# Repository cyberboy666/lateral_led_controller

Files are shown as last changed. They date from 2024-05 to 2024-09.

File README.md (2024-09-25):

# lateral_led_controller

### hardware network controller for addressable led installations 



- this circuit is distributed by __UNDERSCORES__ - _an open video hardware label_ : it is available to purchase - as a pcb, kit or assembled unit - at [underscores.shop](https://underscores.shop/lateral_led_controller/)
- the schematic for the circuit can be found [here](/hardware/schematic.pdf)
- the pcb gerber files for the lastest version can be found [here](/hardware/gerber_latest.zip)
- interactive BOM is [here](https://htmlpreview.github.io/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)
- consider [donating](https://opencollective.com/underscores) to the underscores project to help us continue creating for the commons

## description

_lateral_led_controller_ is a hardware interface that converts [Art-Net](https://art-net.org.uk/), a network protocol for transmitting DMX data over network, into signals that drive addressable LEDs. it can be combined with mapping software (such as my [artnet_led_mapper](https://github.com/cyberboy666/artnet_led_mapper/)) to send arbitrary video onto an led strip canvas

features include:

- receives artnet data via ETHERNET, WIFI or ACCESS_POINT
- natively drive addressable leds [WS281X](https://www.aliexpress.com/item/4001322411818.html) and [APA102](https://www.aliexpress.com/item/32322326979.html)
- supports up to `8` parallel data outs and up to `12` DMX universes for max control over `2000` leds !
- local web interface for easily configuring network / led settings
- flexible dc power input - between 5v to 12v with low-heat / efficient on-board step-down converter
- open source hardware and firmware - can be customized to meet your specific needs

## background

this controller is a companion to my [artnet_led_mapper](https://github.com/cyberboy666/artnet_led_mapper/) application that converts a video feed into artnet for addressable led strip installations. it was built for [lateral movement](https://cyberboy666.com/lateralmovement/) club nights such as seen here:



you can find some more background on this install and process here: [WORKS IN PROGRESS 04 - talk about controlling addressable leds for art installation](https://videos.scanlines.xyz/w/p/tUhDfYqJJPfjovscNMvFRL) 

## demo video

(https://videos.scanlines.xyz/w/2kwtY8TChY21LKqXwgELue)

## hardware options

<details><summary>hardware options</summary>

besides this controller there are some more bits of hardware you will need to realize an _addressable led installation_ - i will outline some suggestions here based on my experience but this will depend on your specific requirements - feel free to [email me](mailto:tim@cyberboy666.com) if you would like individual consulting on this.

### led strips

this controller is configured to support two types of addressable led strips (more can be added by firmware update):

### __WS281X__

ie [neopixels](https://www.adafruit.com/product/2541),  [WS2813 (5v) or WS2815 (12v)](https://www.aliexpress.com/item/4001322411818.html)

- these strips are cheapest - around 5usd for 60/m on aliexpress
- data to them is sent over a single wire (D) but is quite slow (around _800kbps_)
- this means that a maximum of around 240 of these leds can be addressed in series before the refresh rate drops below 30fps
- this controller is designed to be able to address up to 8 seperate WS281X led strips in parallel (outputs D0-D7 on board) for maximum 1920 number of leds in total



### __APA102__

ie [dotstar](https://www.adafruit.com/product/2574) ,  [SK9822](https://www.aliexpress.com/item/32322326979.html)

- these strips cost more - around 10usd for 60/m on aliexpress
- data to them is sent over two wires : ( __D__ata and __C__lock ) but is _very fast_ - (around _24Mbps_ )
- the controller is designed to address a single APA10 led strip by connecting D0 -> Data, D1 -> Clock
- at those speeds there is no need to have parrallel outputs can easily address 2000 leds in series (may need to look into power injection tho)
- they also claim to draw around 1/5 of the power as WS281X (i havnt tested this myself)



## power supply

we ended up using a switching power supply [like this](https://www.aliexpress.com/item/1005002843829663.html) 

- choose voltage based on your strip type (likely to be either 5v or 12v)
- and then power based on the requirement for total number of leds you are using
- you should power the _lateral_led_controller_ from the same supply thats powering the leds (its designed to safely take 5v - 12v input) or atleast ensure the GNDs are connected
- take note on the recommended power wire thickness based on how much current is passing through it (if you use 12v strips then less current is required and therefore thinner wires)



## light diffusers

for most installation settings it is prefered to use some kind of diffuser to help to evenly distribute light. there are many options and information about this topic online

## wiring and connectors

the data lines from _lateral_led_controller_ uses Pluggable Screw Terminals - standard wire (22awg etc) can connect these lines from controller to the strip



theres also the option to use cat5/6 cables to carry multiple data lines from the _lateral_led_controller_ - these are quite cheap, come in long distances and have twisted pairs which should allow for longer runs



personally i prefer running power lines seperately (on [red+black paired wire](https://www.aliexpress.com/item/4000625095039.html) ) - and using [these kinds](https://www.aliexpress.com/item/1005004267277214.html) of barrel / screw connectors to easily plug in / unplug from the installation



most led strips come with these [SM JST 4](https://www.aliexpress.com/item/1005002516911742.html?) connectors pre-soldered to both ends. one option if you dont want to resolder wires / new connectors onto each strip would be to just get some extra of these and create breakouts



### custom adapter boards

i made two little pcb adatpers that may help you with format convertion also - see below for some examples of how you could wire them







</details>

## software options

<details><summary>software options</summary>

any software that can output artnet over a network can be used with _lateral_led_controller_. some programs i have tested it with include:

- my [artnet_led_mapper](https://github.com/cyberboy666/artnet_led_mapper) application
- [resolume](https://resolume.com/)
- [touch designer](https://derivative.ca/UserGuide/TouchDesigner)
- [QLC+](https://www.qlcplus.org/)

</details>

# documentation

this project is fully _open-source hardware_ - all the files required to build it are included in this repo for free. if you have the time and/or skill you can contribute back by collaborating on / testing new designs, improving these docs, making demo videos/other creative content etc. you can also support the project financially by [donating](https://opencollective.com/underscores) directing, or purchasing through the [web shop](https://underscores.shop).

depending on whether you are going fully diy or buying an assembled and tested unit, some of the following guides will be relavent to you. the flow would be:

## ordering parts

<details><summary><b>parts sourcing guide (w/ notes on pcb fabracation )</b> - start here if you are building fully from scatch or have purchased a pcb</summary>

i try to source all the parts i can from either:
- [tayda](https://www.taydaelectronics.com/) ; cheaper for common parts like resistors etc, also good for mechanical parts like switches and buttons
- [mouser](https://www.mouser.de/) ; has lots more options, speciality video ic's, can sometimes cost more (free shipping on orders over 50euros)
- other ; ocationally there will be parts which will need to be sourced elsewhere - usaully either aliexpress, ebay or amazon etc...

take a look at the [full_bom](/hardware/bom/full_bom.csv) for this project to see where i am sourcing each part from

## import into tayda

- go to the [tayda quick order](https://www.taydaelectronics.com/quick-order/) and in bottom corner choose _add from file_
- select the file [tayda_bom.csv](./hardware/bom/tayda_bom.csv) in the BOM folder (you will have to download it first or clone this repo)
- after importing select _add to cart_
- __NOTE:__ the minimum value for resistors is 10, so you may need to modify these values to add to cart (or if they are already modified here you will need to see the  full_bom for actual part QTY) 

- OPTIONAL: it is a good idea to add some dip-ic sockets and 2.54pin headers/sockets to your tayda order if you dont have them around already

## sourcing other parts

this circuit has a few _specific_ parts that can not be sourced from tayda/mouser:

### WT32-ETH01 micro-controller
we are using a [WT32-ETH01](https://www.aliexpress.com/item/1005007279607510.html) ESP32 controller with the LAN8720A chip / ethernet port already attached - this is because it requires specific routing that is easier to get in a module like this - [heres](https://github.com/egnor/wt32-eth01) some more general info about this uC - it should be easy to find with a search on ali/amazon/ebay/etc - if you get it without header pins you can solder the controller straight on to the pcb (using the castellated edges) 



### MP1584EN_5v_stepdown

another pre-soldered module used in this circuit is this [MP1584EN_5v_stepdown](https://www.aliexpress.com/item/1005006005888518.html) - 3A Step-down 5v

its a useful module that allows a wide range of voltage inputs and is much more efficent than standard linear regulators (so producing less heat - which is important for installation work) - you can also solder the board directly onto our pcb with the castellated edges - take note of the direction indicated by arrow on bottom of module



### WeMos_CH340G_USB_to_SERIAL

since the WT32-ETH01 doesnt have an on-board _usb-to-serial_ on the module for uploading firmware this board is designed to work with this [WeMos_CH340G_USB_to_SERIAL](https://www.aliexpress.com/item/1005006642575408.html) one - we are using this because it outputs the command signals that allow for auto-uploading (so we dont need to manually switch to boot mode every time) - you may need to join some pads with solder on the module to select DTS mode for it to work



Screenshot from 2024-09-06 13-56-25

## terminal jacks

the footprints on the pcb for the data line outputs are spaced for __3.5MM__

- im using [KF2EDG RIGHT ANGLE 3.5MM PLUGGABLE](https://www.aliexpress.com/item/1005005511990041.html) terminals in my kits, but this is up to you - standard screw terminal (non-pluggable) like [this](https://www.aliexpress.com/item/1005001333343844.html) could also fit..



## ordering pcbs

you can support this project by buying individual pcbs from the [shop](https://underscores.shop). if you would rather have pcbs fabricated from gerbers directly the file you need is [here](/hardware/gerber_latest.zip)

- i get my pcbs fabricated from [jlcpcb](https://cart.jlcpcb.com/quote) - 5 is the minumum order per design
- upload the zip file with the `add gerber file` button
- the default settings are mostly fine - set the __PCB Qty__ and __PCB Color__ settings (you can check that the file looks correct with pcb veiwer)
- it may be best to combine orders with other pcbs you want to have fab'd since the shipping can cost more than the items - also orginising group buys is a good way to distribute the extra pcbs /costs 
  
i often use jlcpcb because they are reliable, cheap and give you an option of colours. remember though that the cheapest Chinese fab houses are not always the most ethical or environmently friendly - if you can afford it consider supporting local companies. 

  </details>
  
## assembly guide
  
<details><summary><b>assembly guide</b> - start here if you have purchased a diy kit</summary>

## interactive BOM for build guiding

follow this link to view the [interactive BOM](https://htmlpreview.github.io/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)

## general solder advice

- remember to heat pad first (2-3seconds), then add solder, then continue to heat (1-2seconds)

- Checkout the web-comic [soldering is easy](https://mightyohm.com/files/soldercomic/FullSolderComic_EN.pdf) for more soldering advice

## order of assembly

- both the _WT32-ETH01_ controller and the _MP1584EN_5v_stepdown_ module can be soldered directly to the board using the castellated edges (if you would rather use pins/sockets this is fine also - just be aware you may need to use higher standoffs if also mounting a front panel) - these should be soldered before anything else

- next i would solder the resistors, capictors (take note of direction), diodes, transistors etc

- finally would finish with ic's and interface parts - sockets, buttons etc...

</details>

## firmware guide

<details><summary><b>firmware guide</b> - for editing the code & flashing it to your micro-controller</summary>
  
## flashing firmware onto the micro-controller
  
if you have got a kit from the shop the default firmware will be pre-configured - still it could be useful to know how to update firmware / customize your controller.
  
### install guide
  
all _underscores_ projects with micro-controllers use [platformio](https://platformio.org/) with [visual studio code](https://code.visualstudio.com/) to edit, flash and monitor the code.
  
- first download (and unzip) the code in this repo - easiest is [as a zip](https://github.com/cyberboy666/lateral_led_controller/archive/refs/heads/main.zip) or you can clone using git if you are comfortable with this
- next download, install and open [visual studio code](https://code.visualstudio.com/#alt-downloads)
- now open the extension tab within vscode on left vertical menu (or press ctrl-shift-x) and search for `platformio` to install this extension
  


- connect the micro-controller to computer via usb with the __WeMos_CH340G_USB_to_SERIAL__ port, open the software folder of this project (ctrl-k ctrl-o) in vscode and find the _platformio_ commands (either in left vertical menu under _platformio_ or little tick/arrow symbols along bottom blue bar) - `PlatformIO: Upload` should flash the default code to your micro-controller
  


</details>

</details>

## operating guide
  
<details><summary><b>operating guide</b> - start here if you have purchased an assembled unit</summary>



## access settings interface for first time

- power on the circuit by plugging in a 5-12v dc supply into the POWER IN
- using a computer / phone connect to the ACCESS_POINT created by the controller: default name `leds` pw `ledsleds` - you should see the blue _network connected_ led come on when you have connected to this network
- in a browser go to `http://leds.local` (also try `http://192.168.4.1` if that doesnt work ) - you should now see the web interface!
- from here you can set up which connection mode to use, see your controllers ip and also set which led protocol & layout to use - make sure the led settings (led type, number of data lines and number of leds per line ) reflect your installation setup.
- for most installation settings it will be preferable to use wired ethernet connection to send data into this controller - make sure the IP/SUBMASK/GATEWAY settings reflect the ethernet settings being used on the computer this controller is connecting to. __auto assign ethernet connection__ worked from my linux machine but i could not get windows to assign an ip (act as dhcp) - maybe there is some setting or maybe it needs to be done manually from some operating systems such as windows.





## reset button

### soft reset

on the controller board next to the `NETWORK CONNECTED` led is a `CONTROLLER RESET` button - pushing this will reboot the controller -> you should see the _network connected_ light go off for a momement while it resets

### hard reset

if you hold down the `CONTROLLER RESET` button for 5 seconds then release it you should see the `NETWORK CONNECTED` led flashing -> then short pressing the `CONTROLLER RESET` again from this mode will perform a __hard reset__ this means that the _NETWORK TYPE_ is reset back to __ACCESS_POINT__ and all settings are restored to default (you will need to connect to `leds` with pw `ledsleds` again to set up your controller)

this can be helpful if you accidently put the controller into a state with network settings that you can not access the page any more.

(if you get to the flashing led state but do not want to do a hard reset just power down the controller while flashing and your settings will not be wiped)

</details>

### more info

<details><summary><b>how the circuit works</b></summary>
  
[coming soon]
                                                                                                                             
</details>

<details><summary><b>contributing guide</b></summary>
  
if you would like to contribute back to these projects in some way but dont know how the best thing (for now) would be to reach out to me directly ( tim@cyberboy666.com or @cyberboy666 on scanlines forum) - i will be happy to help
  
</details>

## credits & more info

This circuit is distributed through UNDERSCORES – open video hardware label – visit [underscores.shop](https://underscores.shop) for more info

The pcb was designed using KICAD , the booklet was created in LibreOffice Draw

Everything from gerbers, cad files, panels and documentation is freely available online and distributed under CC-BY-SA / open-source licenses – help us contribute to the commons !

Ask any questions or start discussions related to this project on the [scanlines.xyz](https://scanlines.xyz) forum – an online community space dedicated to diy av / electronic media art

You can contact me directly at tim (at) cyberboy666 (dot) com 
Please get in touch if you are interested in hosting a workshop !



thanks to Tor for user testing + detailed feedback and suggestions + help with web interface design. thanks to the Lateral Movement Crew: Leo, Teesh, Wendy, Luke, Sean - for all the work into making these parties happen

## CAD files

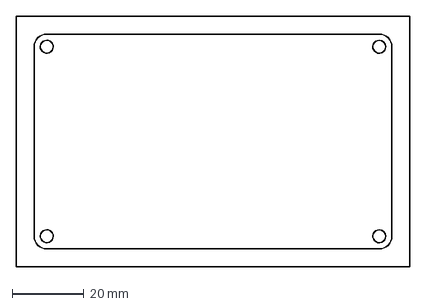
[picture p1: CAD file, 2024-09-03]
panels/back_panel/lateral_led_controller_back_panel-Edge_Cuts.dxf
110.1 x 70.1 mm

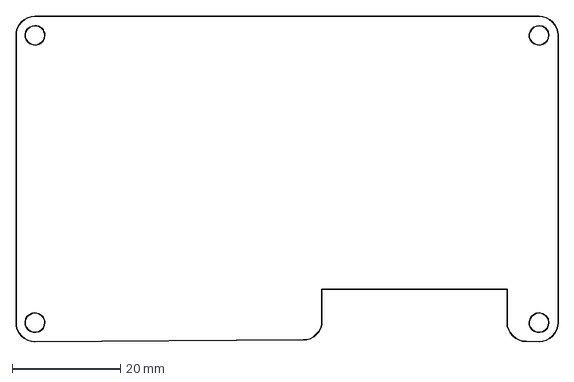
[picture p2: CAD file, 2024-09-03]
panels/front_panel/lateral_led_controller_panel-Edge_Cuts.dxf
100.0 x 60.0 mm

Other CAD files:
panels/front_panel/lateral_led_controller_panel-F_Silkscreen.dxf

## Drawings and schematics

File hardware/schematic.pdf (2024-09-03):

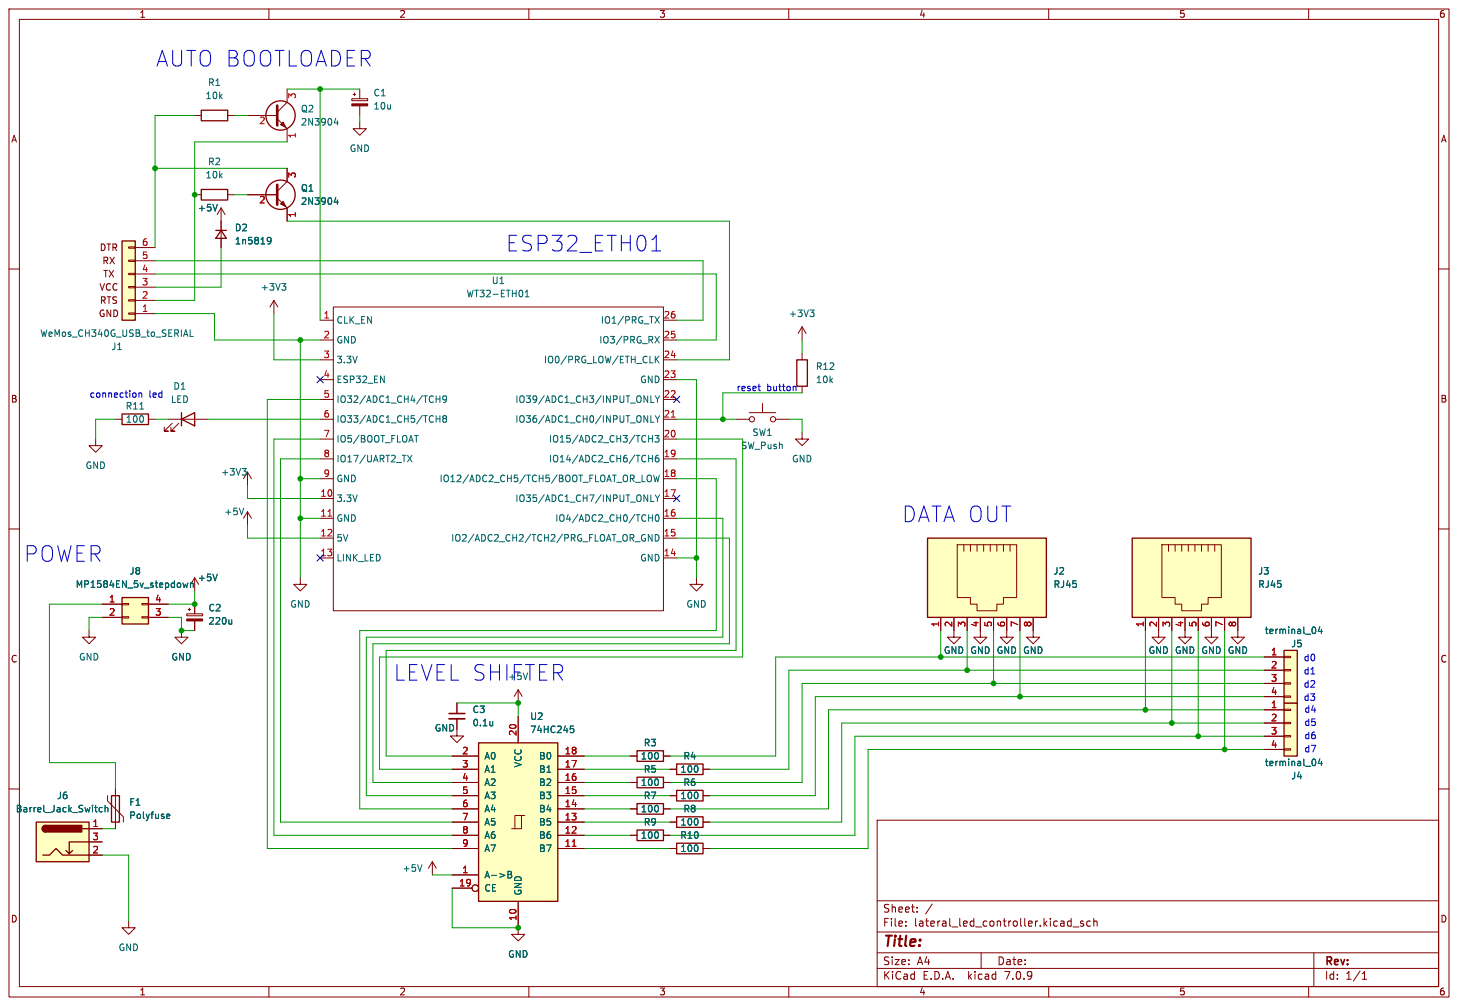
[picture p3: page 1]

8 GND GND GND GND GND J5

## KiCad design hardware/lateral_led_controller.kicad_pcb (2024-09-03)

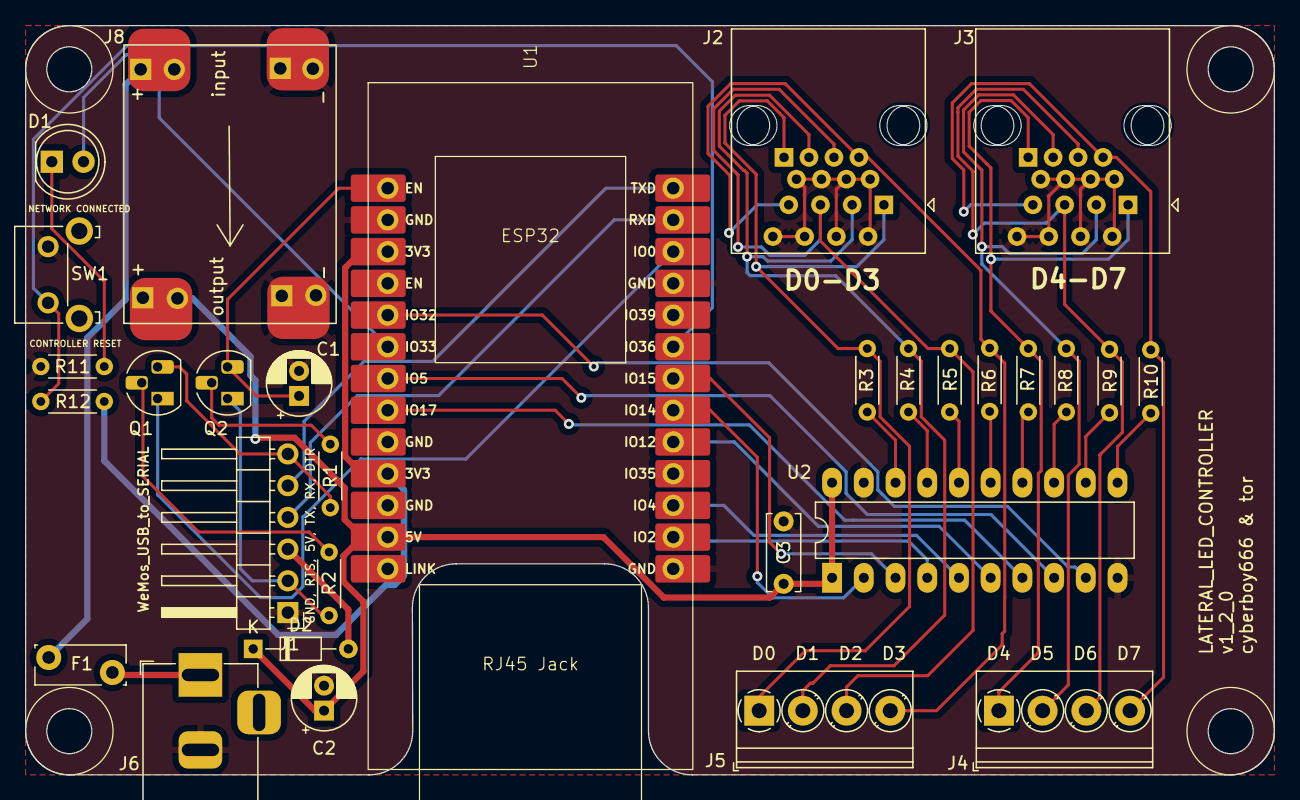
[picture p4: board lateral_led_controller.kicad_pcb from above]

Board: 2 copper layers, 100.0 x 60.0 mm, 30 parts (0 on the bottom side), 41 nets.

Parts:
C1: 10u; CP_Radial_D5.0mm_P2.00mm
C2: 220u; CP_Radial_D5.0mm_P2.00mm
C3: 0.1u; C_Disc_D6.0mm_W2.5mm_P5.00mm
D1: LED; LED_D5.0mm
D2: 1n5819; D_DO-34_SOD68_P7.62mm_Horizontal
F1: Polyfuse; Fuse_Bourns_MF-RG300
J1: WeMos_CH340G_USB_to_SERIAL; PinHeader_1x06_P2.54mm_Horizontal
J2, J3: RJ45; RJ45_Horizontal
J4, J5: terminal_04; TerminalBlock_Phoenix_PT-1,5-4-3.5-H_1x04_P3.50mm_Horizontal
J6: Barrel_Jack_Switch; BarrelJack_Horizontal
J8: MP1584EN_5v_stepdown; MP1584EN_stepdown_module
Q1, Q2: 2N3904; TO-92_HandSolder
R1, R2, R12: 10k; R_Axial_DIN0204_L3.6mm_D1.6mm_P5.08mm_Horizontal
R3, R4, R5, R6, R7, R8, R9, R10, R11: 100; R_Axial_DIN0204_L3.6mm_D1.6mm_P5.08mm_Horizontal
SW1: SW_Push; SW_Tactile_SKHH_Angled
U1: WT32-ETH01
U2: 74HC245; DIP-20_W7.62mm_LongPads

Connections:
+3V3: R12.2, U1.3 (3.3V), U1.10 (3.3V)
+5V: C2.1, C3.1, D2.1 (K), J8.4, U1.12 (5V), U2.1 (A->B), U2.20 (VCC)
GND: C1.2, C2.2, C3.2, J1.1, J2.2, J2.4, J2.6, J2.8, J3.2, J3.4, J3.6, J3.8, J6.2, J8.2, J8.3, R11.1, SW1.2, U1.2 (GND), U1.9 (GND), U1.11 (GND), U1.14 (GND), U1.23 (GND), U2.10 (GND), U2.19 (CE)
unnamed: D1.2 (A), U1.6 (IO33/ADC1_CH5/TCH8)
unnamed: D1.1 (K), R11.2
unnamed: D2.2 (A), J1.3
unnamed: F1.1, J6.1
unnamed: J1.2, Q2.1 (E), R2.1
unnamed: J1.4, U1.25 (IO3/PRG_RX)
unnamed: J1.5, U1.26 (IO1/PRG_TX)
unnamed: J1.6, Q1.3 (C), R1.1
unnamed: J3.1, J4.1, R7.2
unnamed: J3.3, J4.2, R8.2
unnamed: J3.5, J4.3, R9.2
unnamed: J3.7, J4.4, R10.2
unnamed: J2.1, J5.1, R3.2
unnamed: J2.3, J5.2, R4.2
unnamed: J2.5, J5.3, R5.2
unnamed: J2.7, J5.4, R6.2
unnamed: F1.2, J8.1
unnamed: Q1.2 (B), R2.2
unnamed: Q1.1 (E), U1.24 (IO0/PRG_LOW/ETH_CLK)
unnamed: Q2.2 (B), R1.2
unnamed: C1.1, Q2.3 (C), U1.1 (CLK_EN)
unnamed: U1.15 (IO2/ADC2_CH2/TCH2/PRG_FLOAT_OR_GND), U2.4 (A2)
unnamed: U1.16 (IO4/ADC2_CH0/TCH0), U2.5 (A3)
unnamed: U1.7 (IO5/BOOT_FLOAT), U2.8 (A6)
unnamed: U1.18 (IO12/ADC2_CH5/TCH5/BOOT_FLOAT_OR_LOW), U2.6 (A4)
unnamed: U1.19 (IO14/ADC2_CH6/TCH6), U2.2 (A0)
unnamed: U1.20 (IO15/ADC2_CH3/TCH3), U2.3 (A1)
unnamed: U1.8 (IO17/UART2_TX), U2.7 (A5)
unnamed: U1.5 (IO32/ADC1_CH4/TCH9), U2.9 (A7)
unnamed: R12.1, SW1.1, U1.21 (IO36/ADC1_CH0/INPUT_ONLY)
unnamed: R3.1, U2.18 (B0)
unnamed: R4.1, U2.17 (B1)
unnamed: R5.1, U2.16 (B2)
unnamed: R6.1, U2.15 (B3)
unnamed: R7.1, U2.14 (B4)
unnamed: R8.1, U2.13 (B5)
unnamed: R9.1, U2.12 (B6)
unnamed: R10.1, U2.11 (B7)

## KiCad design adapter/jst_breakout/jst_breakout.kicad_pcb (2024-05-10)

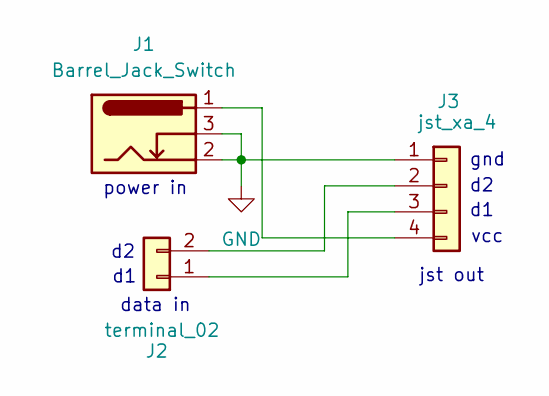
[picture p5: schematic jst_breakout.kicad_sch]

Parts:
J1: Barrel_Jack_Switch; BarrelJack_Horizontal
J2: terminal_02
J3: jst_xa_4; JST_XA_B04B-XASK-1-A_1x04_P2.50mm_Vertical

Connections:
GND: J1.2, J1.3, J3.1
unnamed: J2.1, J3.3
unnamed: J2.2, J3.2
unnamed: J1.1, J3.4

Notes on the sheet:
jst out
vcc
data in
power in
gnd

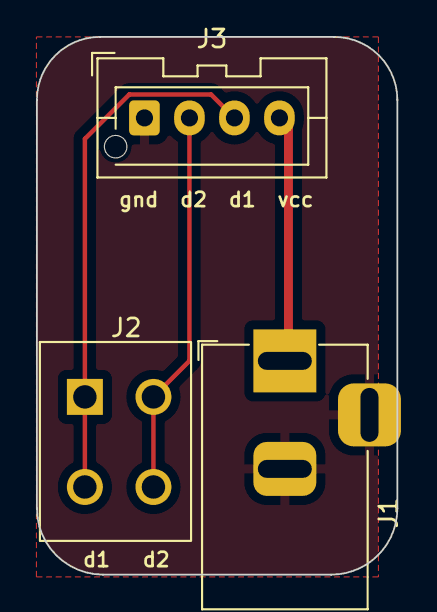
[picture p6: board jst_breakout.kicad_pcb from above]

Board: 2 copper layers, 20.0 x 29.9 mm, 3 parts (0 on the bottom side), 4 nets.

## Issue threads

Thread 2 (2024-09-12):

KNOWN ISSUE: some artnet packets are dropped when many universes are sent to the controller

cyberboy666, 2024-09-12:
_tl;dr - if using ethernet connection then switching to 10mbps can improve performance - even so a maximum of 12 universes (~2000 leds) is recommended due to this current bottleneck - i do believe it is possible to atleast x2 this with firmware updates_

## details of the issue

in the artnet protocol up to 512 values can be sent in a single packet - this is called a __universe__ and since we need 3 values per led (rgb) then a single universe can control up to 170 leds. if we want to control more than this we need to split this information across multiple universes (packets)

when sending lots of universes (our installation needed 12) i was observing that packets were being dropped. on the controller side i printed out to serial average number of universes collected per frame so i could track this.

the amount of dropped packets reduced significantly when i switched from 100mbps to 10mbps wired connection.

its my assumption that since these multiple universes for the same frame are being sent within very quick succession that the esp32 buffer is overflowing / not able to process them all in time.

this [discussion on reddit](https://www.reddit.com/r/FastLED/comments/14mfelz/comment/jq1u1g3/) seems to support this assumption:

> It can be done. The limiting factor is 10 mb/s ethernet. If you use 100 mb/s you will lose some packets since Resolume sends them in bursts and the receive buffer will overflow. At 10 mb/s you can send 5400 pixels at 60 fps.

(i could not reproduce 5400 pixels at 60 fps at 10mbps but i think they are using a [different library](https://github.com/hpwit/artnetesp32v2) underneath to us here)

## firmware improvements ?

i spent some time looking into this but did not find a way to improve it further than switching to 10mbps connection.

for now im listing the specs on this controller to supporting up to `12 universes` = 12*170= __2040 leds__ which is the max i have confirmed it to work smoothly for.

theres also the other bottleneck of the protocol speed of WS281X which runs at 800kbps which allows for up to 240 leds per data line (while updating above 30fps) which results in a total of 240*8 = __1920 leds__

however it does sound like there are other optimizations available (overclocking ws281x slightly + less other overheads maybe?) that can allow even ws281x leds to output 540 pixels per line at 60fps (total of 4320 leds which is around 26 universes):

> It takes 16.2 ms plus begin and end pulses. That's more than the 16.6 milliseconds that one frame at 60 fps takes. You can either run your system at less than 60 fps or you can overdrive your leds at 833 kHz instead of the standard 800 kHz. At 833 kHz it takes 15.6 ms plus begin and end pulses to send 540 pixels. At that speed you can do 60 fps

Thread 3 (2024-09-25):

the hardware relies on some specfic modules that may become hard to source

cyberboy666, 2024-09-25:
this project uses 3 prebuilt modules in its BOM:

- [WT32-ETH01](https://www.aliexpress.com/item/1005007279607510.html)
- [MP1584EN_5v_stepdown](https://www.aliexpress.com/item/1005006005888518.html)
- [WeMos_CH340G_USB_to_SERIAL](https://www.aliexpress.com/item/1005006642575408.html)

this is convenient for a few reasons:

-  reduces the total amount of parts needed to source and solder
- allows for use and space saving of smd components while keeping assembly beginner friendly
- sometimes is cheaper than buying those parts on the module individually since they are bought and assembled in bulk
- is easier to develop from the original one-off design this circuit was based on

however it has the drawback that it could make sourcing these modules in the future more difficult - when you use a footprint for a known part from mouser etc there is some expectation that this part will continue to be available in the future. when you just buy a module from aliexpress it is possible this module will stop being made or change its footprint etc.

for this reason it could make sense to design a version of this controller that does not rely on these module and instead has built in:

- the esp32 ic and related components
- the ethernet chip and related components
- the step-down converter ic and related components
- the usb-to-serial ic and related components..

this would feel like a more professional and future-proofed design (at the cost being less diy friendly.. maybe costing more etc)

whether this upgrade is worth doing depends how popular (if at all) this project becomes - if only a few people want these i think it is easier to keep the current hardware design...

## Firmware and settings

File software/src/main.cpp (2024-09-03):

#include <Arduino.h>
#include <FastLED.h>
#include <ArtnetETH.h>
#include <ArtnetWiFi.h>
#include <ESPmDNS.h>

#define DEBUG_ETHERNET_WEBSERVER_PORT Serial
#define _ETHERNET_WEBSERVER_LOGLEVEL_ 3
#define ARDUINOOSC_DEBUGLOG_ENABLE

#include <Wire.h>
#include <WebServer_WT32_ETH01.h>
#include <Preferences.h>
#include "Bounce2.h"

#include "html_content.h"

WebServer server(80);
Preferences preferences;
ArtnetReceiver artnetEth;
// ArtnetWiFiReceiver artnetWifi;
Bounce debouncer = Bounce();

const int buttonPin = 36;
const int ledPin = 33;
int ledState = LOW;
bool ipReset = false;
unsigned long currentMillis = 0;
unsigned long lastPrintTime = 0;
unsigned long lastLedTime = 0;
unsigned long ledFrequency = 1;

int ApConnections = 0;
bool isWifiConnected = false;

// all the config variables and there defaults defined here:
// network settings
String network_type = "ACCESS_POINT";
bool eth_auto = false;
String eth_ip = "192.168.5.100";
String eth_gw = "192.168.1.1";
String eth_sn = "255.255.255.0";
bool ap_auto = true;
String ap_ssid = "leds";
String ap_pw = "ledsleds";
String ap_ip = "192.168.4.1";
String ap_gw = "192.168.4.1";
String ap_sn = "255.255.255.0";
bool wifi_auto = true;
String wifi_ssid = "leds";
String wifi_pw = "ledsleds";
String wifi_ip = "192.168.1.101";
String wifi_gw = "192.168.1.1";
String wifi_sn = "255.255.255.0";
// led settings
String led_type = "WS2815";
int num_outputs = 1;
int num_leds[8];
int frame_time = 20;
bool use_artsync = false;

String subdomain = "leds";
CRGB leds[2000];
int numUniverse = 0;
uint16_t universeMask = 0;
uint16_t expectedUniverseMask = 0;
uint8_t universeCount = 0;
#define DATA_PIN_0 14
#define DATA_PIN_1 15
#define DATA_PIN_2 2
#define DATA_PIN_3 4
#define DATA_PIN_4 12
#define DATA_PIN_5 17
#define DATA_PIN_6 5
#define DATA_PIN_7 32
unsigned long previousMillis = 0;
bool haveUniverse[12] = {false};
bool artsync_flag = false;
int totalUniverseCount = 0;
int frameCount = 0;
int totalTime = 0;

String boolToString(bool value)
{
  return value ? "true" : "false";
}

IPAddress ipFromString(String inputString)
{
  IPAddress thisIp;
  thisIp.fromString(inputString);
  if (!thisIp.fromString(inputString))
  {
    Serial.println("from string looks bad");
  }
  return thisIp;
}

String getCurrentIp()
{
  if (network_type == "ETHERNET")
  {
    return ETH.localIP().toString();
  }
  else if (network_type == "ACCESS_POINT")
  {
    return WiFi.softAPIP().toString();
  }
  else
  {
    return WiFi.localIP().toString();
  }
}

void WiFiEvent(WiFiEvent_t event)
{
  switch (event)
  {
  case SYSTEM_EVENT_STA_CONNECTED:
    Serial.println("Connected to Wi-Fi.");
    isWifiConnected = true;
    break;
  case SYSTEM_EVENT_STA_DISCONNECTED:
    Serial.println("Disconnected from Wi-Fi.");
    isWifiConnected = false;
    break;
  case 12:
    Serial.println("A device connected to the access point.");
    ApConnections++;
    break;
  case 13:
    Serial.println("A device disconnected from the access point.");
    ApConnections--;
    break;
  default:
    Serial.print("Unknown event. Event code: ");
    Serial.println(event);
    break;
  }
}

bool isNetworkConnected()
{
  if (network_type == "ETHERNET")
  {
    return WT32_ETH01_eth_connected;
  }
  else if (network_type == "ACCESS_POINT")
  {
    return ApConnections > 0;
  }
  else
  {
    return isWifiConnected;
  }
}

void loadFromPreferences()
{

  preferences.begin("my-app", false);
  network_type = preferences.getString("network_type", network_type);
  eth_auto = preferences.getBool("eth_auto", eth_auto);
  eth_ip = preferences.getString("eth_ip", eth_ip);
  eth_sn = preferences.getString("eth_sn", eth_sn);
  eth_gw = preferences.getString("eth_gw", eth_gw);
  ap_auto = preferences.getBool("ap_auto", ap_auto);
  ap_ssid = preferences.getString("ap_ssid", ap_ssid);
  ap_pw = preferences.getString("ap_pw", ap_pw);
  ap_ip = preferences.getString("ap_ip", ap_ip);
  ap_sn = preferences.getString("ap_sn", ap_sn);
  ap_gw = preferences.getString("ap_gw", ap_gw);
  wifi_auto = preferences.getBool("wifi_auto", wifi_auto);
  wifi_ssid = preferences.getString("wifi_ssid", wifi_ssid);
  wifi_pw = preferences.getString("wifi_pw", wifi_pw);
  wifi_ip = preferences.getString("wifi_ip", wifi_ip);
  wifi_sn = preferences.getString("wifi_sn", wifi_sn);
  wifi_gw = preferences.getString("wifi_gw", wifi_gw);
  led_type = preferences.getString("led_type", led_type);
  num_outputs = preferences.getInt("num_outputs", num_outputs);
  for (int i = 0; i < 8; i++)
  {
    num_leds[i] = preferences.getInt(("num_leds" + String(i)).c_str(), 0);
  }
  frame_time = preferences.getInt("frame_time", frame_time);
  use_artsync = preferences.getBool("use_artsync", use_artsync);
  preferences.end(); // Close preferences
}

void clearPreferences()
{

  preferences.begin("my-app", false);
  preferences.clear();
  preferences.end();
}

void updateToPreferences()
{

  preferences.begin("my-app", false);
  preferences.putString("network_type", network_type);
  preferences.putBool("eth_auto", eth_auto);
  preferences.putString("eth_ip", eth_ip);
  preferences.putString("eth_sn", eth_sn);
  preferences.putString("eth_gw", eth_gw);
  preferences.putBool("ap_auto", ap_auto);
  preferences.putString("ap_ssid", ap_ssid);
  preferences.putString("ap_pw", ap_pw);
  preferences.putString("ap_ip", ap_ip);
  preferences.putString("ap_sn", ap_sn);
  preferences.putString("ap_gw", ap_gw);
  preferences.putBool("wifi_auto", wifi_auto);
  preferences.putString("wifi_ssid", wifi_ssid);
  preferences.putString("wifi_pw", wifi_pw);
  preferences.putString("wifi_ip", wifi_ip);
  preferences.putString("wifi_sn", wifi_sn);
  preferences.putString("wifi_gw", wifi_gw);
  preferences.putString("led_type", led_type);
  preferences.putInt("num_outputs", num_outputs);
  for (int i = 0; i < 8; i++)
  {
    preferences.putInt(("num_leds" + String(i)).c_str(), num_leds[i]);
  }
  preferences.putInt("frame_time", frame_time);
  preferences.putBool("use_artsync", use_artsync);
  preferences.end(); // Close preferences
}

String replaceInHtml(String html)
{
  String current_ip = getCurrentIp();
  html.replace("{{current_ip}}", current_ip);

  html.replace("{{network_type}}", network_type);
  html.replace("{{eth_auto}}", boolToString(eth_auto));
  html.replace("{{eth_ip}}", eth_ip);
  html.replace("{{eth_gw}}", eth_gw);
  html.replace("{{eth_sn}}", eth_sn);
  html.replace("{{ap_auto}}", boolToString(ap_auto));
  html.replace("{{ap_ssid}}", ap_ssid);
  html.replace("{{ap_pw}}", ap_pw);
  html.replace("{{ap_ip}}", ap_ip);
  html.replace("{{ap_gw}}", ap_gw);
  html.replace("{{ap_sn}}", ap_sn);
  html.replace("{{wifi_auto}}", boolToString(wifi_auto));
  html.replace("{{wifi_ssid}}", wifi_ssid);
  html.replace("{{wifi_pw}}", wifi_pw);
  html.replace("{{wifi_ip}}", wifi_ip);
  html.replace("{{wifi_gw}}", wifi_gw);
  html.replace("{{wifi_sn}}", wifi_sn);
  html.replace("{{led_type}}", led_type);
  Serial.print("num_outputs: ");
  Serial.print(num_outputs);
  html.replace("{{num_outputs}}", String(num_outputs));
  for (int i = 0; i < 8; i++)
  {
    html.replace("{{num_leds" + String(i) + "}}", String(num_leds[i]));
  }
  html.replace("{{frame_time}}", String(frame_time));
  html.replace("{{use_artsync}}", boolToString(use_artsync));
  return html;
}

void updateFromServer()
{

  network_type = server.arg("network_type");
  eth_auto = server.arg("eth_auto") == "true";
  eth_ip = server.arg("eth_ip");
  eth_gw = server.arg("eth_gw");
  eth_sn = server.arg("eth_sn");
  ap_auto = server.arg("ap_auto") == "true";
  ap_ssid = server.arg("ap_ssid");
  if ((server.arg("ap_pw").length() > 7))
  {
    ap_pw = server.arg("ap_pw");
  }
  ap_ip = server.arg("ap_ip");
  ap_gw = server.arg("ap_gw");
  ap_sn = server.arg("ap_sn");
  wifi_auto = server.arg("wifi_auto") == "true";
  wifi_ssid = server.arg("wifi_ssid");
  wifi_pw = server.arg("wifi_pw");
  wifi_ip = server.arg("wifi_ip");
  wifi_gw = server.arg("wifi_gw");
  wifi_sn = server.arg("wifi_sn");
  led_type = server.arg("led_type");
  num_outputs = server.arg("num_outputs").toInt();
  for (int i = 0; i < 8; i++)
  {
    num_leds[i] = server.arg("num_leds" + String(i)).toInt();
  }
  frame_time = server.arg("frame_time").toInt();
  use_artsync = server.arg("use_artsync") == "true";
}

void handleRoot()
{
  String htmlContent = replaceInHtml(index_html);
  server.send(200, "text/html", htmlContent);
}

void handleForm()
{

  updateFromServer();
  updateToPreferences();

  String response_html = "";
  response_html += "Settings updated successfully - return to <a href='http://leds.local'>settings page</a>";
  server.send(200, "text/html", response_html);
  // ETH.config(ipFromString(eth_ip), ipFromString(eth_gw), ipFromString(eth_sn));
  delayMicroseconds(2000);
  ESP.restart();
}

void handleNotFound()
{
  String message = F("File Not Found\n\n");

  message += F("URI: ");
  message += server.uri();
  message += F("\nMethod: ");
  message += (server.method() == HTTP_GET) ? F("GET") : F("POST");
  message += F("\nArguments: ");
  message += server.args();
  message += F("\n");

  for (uint8_t i = 0; i < server.args(); i++)
  {
    message += " " + server.argName(i) + ": " + server.arg(i) + "\n";
  }

  server.send(404, F("text/plain"), message);
}

void buttonAndLedUpdate()
{

  debouncer.update();
  // toggle ipReset mode on long press (flashing led) and restart controller on short press,
  if (debouncer.rose())
  {
    Serial.println("button pressed");
    if (debouncer.previousDuration() < 2000)
    { // button released
      Serial.println("-------- short press");
      if (ipReset)
      {
        // delayMicroseconds(2000);
        // network_type = "ETHERNET";
        // updateToPreferences();
        clearPreferences();
      }
      ESP.restart();
    }
    else
    {
      Serial.println("-------- long press");
      ipReset = !ipReset;
    }
  }

  // flash led if in ipReset mode otherwise led off if ETH not connected and led on if connected
  if (ipReset)
  {
    ledFrequency = 100;
  }
  else if (isNetworkConnected())
  {
    ledFrequency = 1;
  }
  else
  {
    ledFrequency = 0;
  }

  if (ledFrequency == 0)
  {
    digitalWrite(ledPin, 0);
  }
  else if (ledFrequency == 1)
  {
    digitalWrite(ledPin, 1);
  }
  else if (currentMillis - lastLedTime >= ledFrequency)
  {
    Serial.print("led flashing ??");
    ledState = (ledState == LOW) ? HIGH : LOW;
    digitalWrite(ledPin, ledState);
    lastLedTime = currentMillis;
  }
}

void artnetCallback(const uint32_t univ, const uint8_t *data, const uint16_t size)
{
  universeMask |= (1 << univ);
  for (size_t pixel = 0; pixel < 170; ++pixel)
  {
    size_t idx = pixel * 3;
    uint16_t offset_pixel = univ * 170 + pixel;
    leds[offset_pixel].r = data[idx + 0];
    leds[offset_pixel].g = data[idx + 1];
    leds[offset_pixel].b = data[idx + 2];
  }
}

void artsyncCallback()
{
  // Serial.println("ARTSYNC");
  artsync_flag = true;
}

void ledSetup()
{

  int fastled_index[8];
  int subtotal = 0;
  for (int i = 0; i < 8; i++)
  {
    fastled_index[i] = subtotal;
    subtotal = subtotal + num_leds[i];
  }
  numUniverse = subtotal / 170 + 1;
  Serial.print("the numUniverses are: ");
  Serial.println(numUniverse);
  expectedUniverseMask = (1 << numUniverse) - 1;

  if (led_type == "WS2815")
  {
    // Serial.print(i);
    // Serial.print(" - start #: ");
    // Serial.print(fastled_index[i]);
    // Serial.print(" - amount #: ");
    // Serial.print(num_leds[i]);
    if (0 < num_outputs)
    {
      FastLED.addLeds<WS2812B, DATA_PIN_0>(leds, fastled_index[0], num_leds[0]);
    }
    if (1 < num_outputs)
    {
      FastLED.addLeds<WS2812B, DATA_PIN_1>(leds, fastled_index[1], num_leds[1]);
    }
    if (2 < num_outputs)
    {
      FastLED.addLeds<WS2812B, DATA_PIN_2>(leds, fastled_index[2], num_leds[2]);
    }
    if (3 < num_outputs)
    {
      FastLED.addLeds<WS2812B, DATA_PIN_3>(leds, fastled_index[3], num_leds[3]);
    }
    if (4 < num_outputs)
    {
      FastLED.addLeds<WS2812B, DATA_PIN_4>(leds, fastled_index[4], num_leds[4]);
    }
    if (5 < num_outputs)
    {
      FastLED.addLeds<WS2812B, DATA_PIN_5>(leds, fastled_index[5], num_leds[5]);
    }
    if (6 < num_outputs)
    {
      FastLED.addLeds<WS2812B, DATA_PIN_6>(leds, fastled_index[6], num_leds[6]);
    }
    if (7 < num_outputs)
    {
      FastLED.addLeds<WS2812B, DATA_PIN_7>(leds, fastled_index[7], num_leds[7]);
    }
  }
  else if (led_type == "APA102")
  {
    FastLED.addLeds<APA102, DATA_PIN_0, DATA_PIN_1>(leds, 0, num_leds[0]);
  }
}

void setup()
{
  Serial.begin(115200);
  pinMode(buttonPin, INPUT_PULLUP);
  pinMode(ledPin, OUTPUT);
  digitalWrite(ledPin, LOW);
  debouncer.attach(buttonPin);
  debouncer.interval(5); // interval in ms
  delay(4000);
  Serial.println("begin");

  // clearPreferences();
  loadFromPreferences();
  // ap_pw = "ledsleds";
  WT32_ETH01_onEvent();
  if (network_type == "ETHERNET")
  {
    // set up ethernet connection
    ETH.begin(ETH_PHY_ADDR, ETH_PHY_POWER);
    if (!eth_auto)
    {
      ETH.config(ipFromString(eth_ip), ipFromString(eth_gw), ipFromString(eth_sn));
    }
  }
  else if (network_type == "ACCESS_POINT")
  {
    WiFi.onEvent(WiFiEvent);
    WiFi.softAP(ap_ssid, ap_pw);
    Serial.print("ap_sn: ");
    Serial.println(ap_sn);
    Serial.print("ipFromString(ap_sn): ");
    Serial.println(ipFromString(ap_sn));
    if (!ap_auto)
    {
      WiFi.softAPConfig(ipFromString(ap_ip), ipFromString(ap_gw), ipFromString(ap_sn));
    }
    // while (WiFi.status() != WL_CONNECTED) {
    //   Serial.print(".");
    //   delay(500);
    // }
    Serial.print("WiFi connected, IP = ");
    Serial.println(WiFi.softAPIP());
    Serial.print("WiFi.status(): ");
    Serial.println(WiFi.status());
  }
  else if (network_type == "WIFI")
  {
    WiFi.begin(wifi_ssid, wifi_pw);
    if (!wifi_auto)
    {
      WiFi.config(ipFromString(wifi_ip), ipFromString(wifi_gw), ipFromString(wifi_sn));
    }
    Serial.print("WiFi connected, IP = ");
    Serial.println(WiFi.localIP());
    WiFi.onEvent(WiFiEvent);
  }

  // WT32_ETH01_waitForConnect();
  if (!MDNS.begin(subdomain))
  {
    Serial.println("Error setting up mDNS");
  }

  server.on(F("/"), handleRoot);
  server.on("/submit", HTTP_POST, handleForm);
  server.onNotFound(handleNotFound);
  server.begin();

  Serial.print(F("HTTP EthernetWebServer is @ IP : "));
  Serial.println(ETH.localIP());

  ledSetup();
  artnetEth.begin();
  artnetEth.verbose(true);
  artnetEth.subscribe(artnetCallback);
  if (use_artsync)
  {
    artnetEth.subscribeArtsync(artsyncCallback);
  }
}

void loop()
{
  currentMillis = millis();
  server.handleClient();
  buttonAndLedUpdate();
  // MDNS.update();
  universeMask = 0;
  universeCount = 0;

  while (true)
  {
    artnetEth.parse();
    if (universeMask == expectedUniverseMask || artsync_flag)
    {
      break;
    }
    if (millis() - currentMillis >= frame_time)
    {
      break;
    }
  }
  for (int i = 0; i < 12; i++)
  {
    if (universeMask & (1 << i))
    {
      universeCount++;
    }
  }

  artsync_flag = false;
  frameCount++;
  totalUniverseCount = totalUniverseCount + universeCount;
  // Serial.println("complete frame - updating leds");
  FastLED.show();

  if (frameCount % 500 == 0)
  {
    Serial.print("current IP is: ");
    Serial.println(getCurrentIp());
    float result = float(totalUniverseCount) / frameCount;
    Serial.print("average number universes collected: ");
    Serial.print(result);
    Serial.print(" - average frame time: ");
    float time = float(millis() - totalTime) / frameCount;
    Serial.println(time);
    frameCount = 0;
    totalUniverseCount = 0;
    totalTime = millis();
  }
}

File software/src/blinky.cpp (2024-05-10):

// #include <Arduino.h>

// const int ledPin = 33;

// void setup() {
//   // Initialize the LED pin as an output
//   Serial.begin(115200);
//   pinMode(ledPin, OUTPUT);
// }

// void loop() {
//   // Turn the LED on
//   digitalWrite(ledPin, HIGH);
//   Serial.println("HIGH");
//   delay(1000);  // Wait for 1 second

//   // Turn the LED off
//   digitalWrite(ledPin, LOW);
//   Serial.println("LOW");
//   delay(1000);  // Wait for 1 second
// }

// // #include <Arduino.h>
// // #include <WiFi.h>

// // const char* ssid = "YourAPSSID";
// // const char* password = "YourAPPassword";

// // void WiFiEvent(WiFiEvent_t event) {
// //     switch (event) {
// //         case SYSTEM_EVENT_AP_STACONNECTED:
// //             Serial.println("A device connected to the access point.");
// //             break;
// //         case SYSTEM_EVENT_AP_STADISCONNECTED:
// //             Serial.println("A device disconnected from the access point.");
// //             break;
// //         default:
// //             Serial.println("Unknown event.");
// //             break;
// //     }
// // }


// // void setup() {
// //     Serial.begin(115200);

// //     // Register WiFi event handler callbacks
// //     WiFi.onEvent(WiFiEvent);

// //     // Start the access point
// //     WiFi.softAP(ssid, password);

// //     delay(1000);
// //     Serial.print("Access Point IP address: ");
// //     Serial.println(WiFi.softAPIP());
// // }

// // void loop() {
// //     // Your code here
// // }

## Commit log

2024-03-12 updating the code and circuit
    [ethernet_led_controller.kicad_pcb, ethernet_led_controller.kicad_sch, ethernet_led_controller_panel.kicad_pcb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]
2024-05-10 update hardware and software
    [ethernet_led_controller.kicad_pcb, jst_breakout.kicad_pcb, rj45_breakout.kicad_pcb]
2024-05-13 updating any changes in hre ?
    [ethernet_led_controller_panel.kicad_pcb]
2024-05-21 Added kicad & affinity lockfiles to ignore
2024-05-23 updating hardware for v1_1_0 - change layouts etc
    [ethernet_led_controller.kicad_pcb, ethernet_led_controller.kicad_sch, ethernet_led_controller_back_panel.kicad_pcb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]
2024-07-05 updated board to use 4x terminal blocks
    [ethernet_led_controller.kicad_pcb, ethernet_led_controller.kicad_sch, ethernet_led_controller_panel.kicad_pcb]
2024-08-01 update hardware to v1_1_0
    [ethernet_led_controller-B_Cu.gbr, ethernet_led_controller-B_Mask.gbr, ethernet_led_controller-B_Paste.gbr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]
2024-09-03 update hardware to v1_2_0
    [ethernet_led_controller-B_Cu.gbr, ethernet_led_controller-B_Mask.gbr, ethernet_led_controller-B_Paste.gbr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]
2024-09-03 rename the project
    [lateral_led_controller.kicad_pcb, lateral_led_controller.kicad_sch, lateral_led_controller_back_panel-Edge_Cuts.dxf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]
